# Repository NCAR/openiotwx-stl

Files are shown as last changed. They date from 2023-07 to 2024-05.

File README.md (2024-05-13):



# openIoTwx STL File Repository

## Base Configuration

The base configuration can capture the following:

* temperature / pressure / humidity
* PM2.5

The configuration consists of:

* a 3.8" 3 opening wxOrb (non-imprint)
* a basic shield housing 
* a basic AQ housing (2 part hooded)
* 1 PVC adapter
* 4 PVC rings
* 2 closed endcaps
* 1 vented endcap

**Print time is estimated at 37.5h on Ender 3 S3 at 60mm/s, PLA+**.

| Part | Location | Est. Print Time | Notes | 
|:---:| :---: | :--: | :-- |
| 3.8" Housing (3 opening) | [./housing/orb38_housing_3open.stl](./housing/orb38_housing_3open.stl) | 12h | 20-25% infill; positioned thread side down |
| basic shield housing ( for BME680) | housing (MF) [./shield/mushroom_shield_MF.stl](./shield/mushroom_shield_MF.stl) | 6h | print cup side up / (M) thread down; use limited support to end of thread for stability; 25% infill |
|a basic AQ housing (2 part hooded) | base (M) [./aq/aq_grill_base_M.stl](./aq/aq_grill_base_M.stl); <br/>vented lid [./aq/aq_grill_lid.stl](./aq/aq_grill_lid.stl)  | **base**: 4h; **lid**: 2h | **base**: print on side with tree support (@2% infill), 20-25% infill everywhere else; **lid**: print grill side down, 20-25% infill  |
| PVC adapter | [./pvcadapter/knurled_pvc_adapter_M.stl](./pvcadapter/knurled_pvc_adapter_M.stl) | 3h | print thread side up, 30-40% infill for maximum strength |
| PVC Rings (4x) | [./solarpanel/solarpanel_ring_clamp_11mm.stl](./solarpanel/solarpanel_ring_clamp_11mm.stl) | 6h | print flat side to plate, 30-40% infill for maximum strength |
| Closed endcaps (2x) | [./endcaps/closed_endcap.stl](./endcaps/closed_endcap.stl) | 3h | flat (cap) side to plate, 30-40% infill for maximum strength |
| Vented endcap (1x) | [./endcaps/vented_endcap.stl](./endcaps/vented_endcap.stl) | 1.5h | flat (vented) side to plate, 30-40% infill for maximum strength |

## Project Links

* openIoTwx Hub :  [https://github.com/NCAR/openiotwx-hub](https://github.com/NCAR/openiotwx-hub)

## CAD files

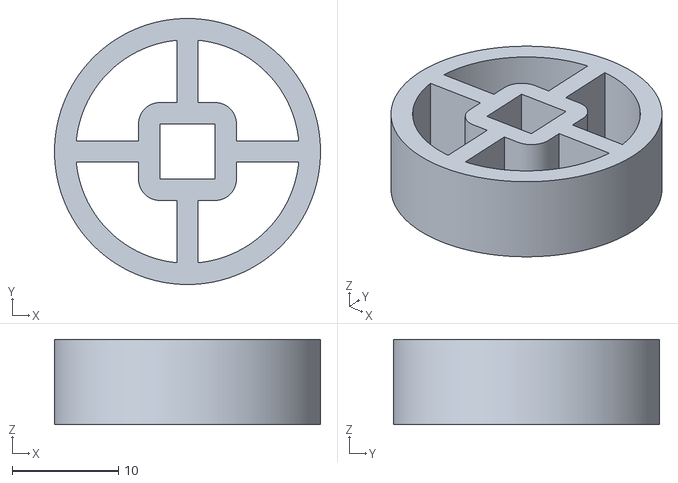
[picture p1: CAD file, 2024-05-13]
accessories/sensor_stand/Inner Base.stl
25.0 x 25.0 x 8.00

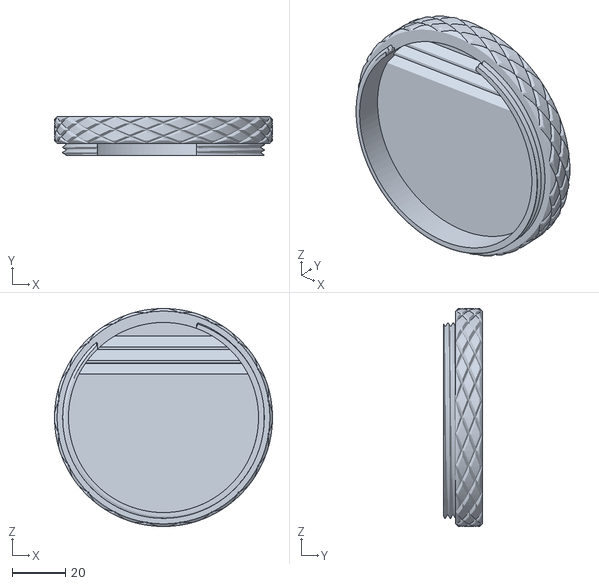
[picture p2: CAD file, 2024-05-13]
aq/aq_grill_lid.stl
82.0 x 14.5 x 82.0

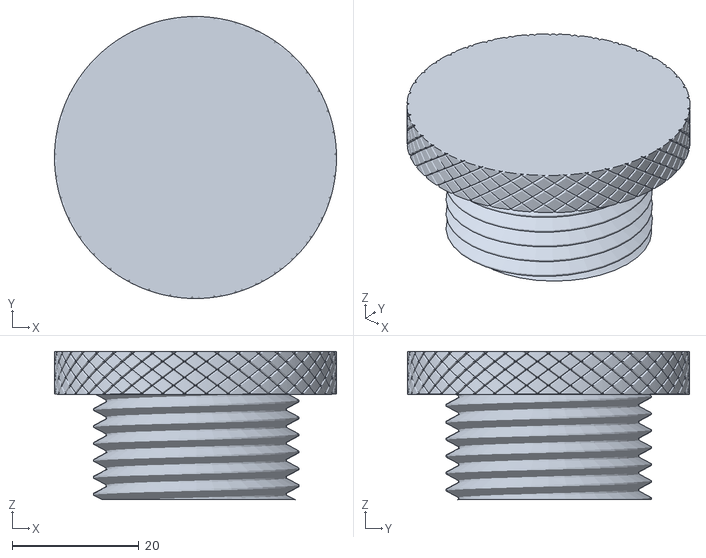
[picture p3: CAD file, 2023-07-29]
endcaps/closed_endcap.stl
44.5 x 44.5 x 23.4

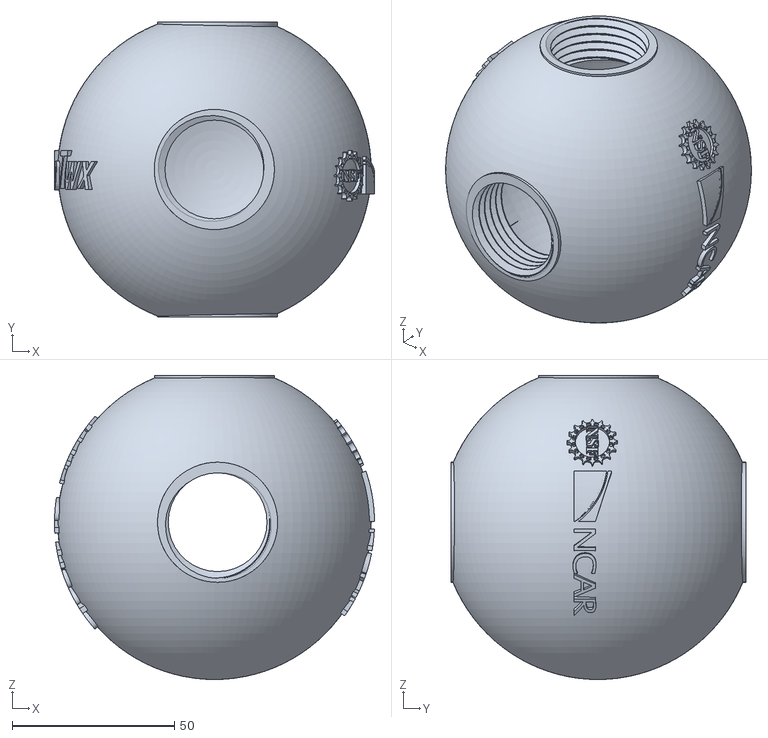
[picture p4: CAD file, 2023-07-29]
housing/orb38_housing_3open.stl
98.5 x 91.0 x 93.6

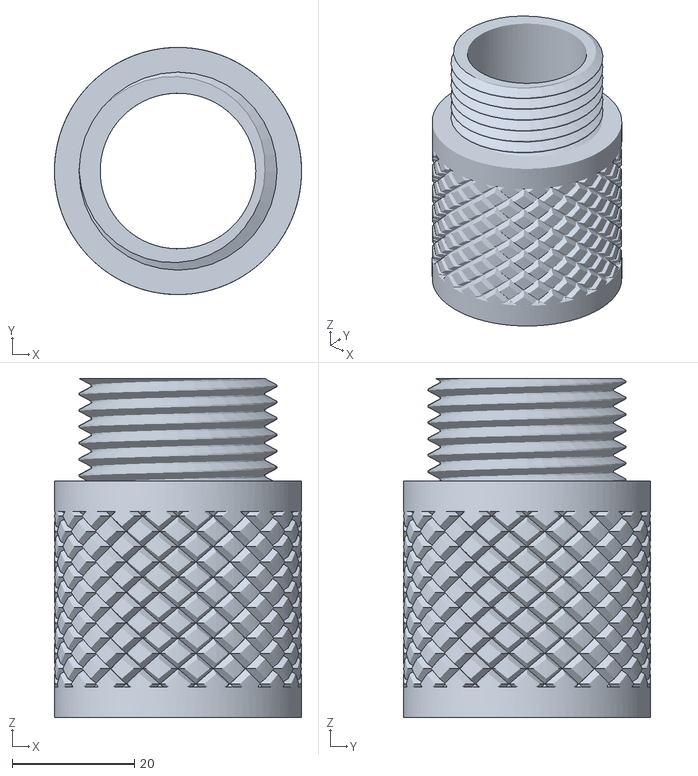
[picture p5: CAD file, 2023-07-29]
pvcadapter/knurled_pvc_adapter_M.stl
40.5 x 40.5 x 55.6

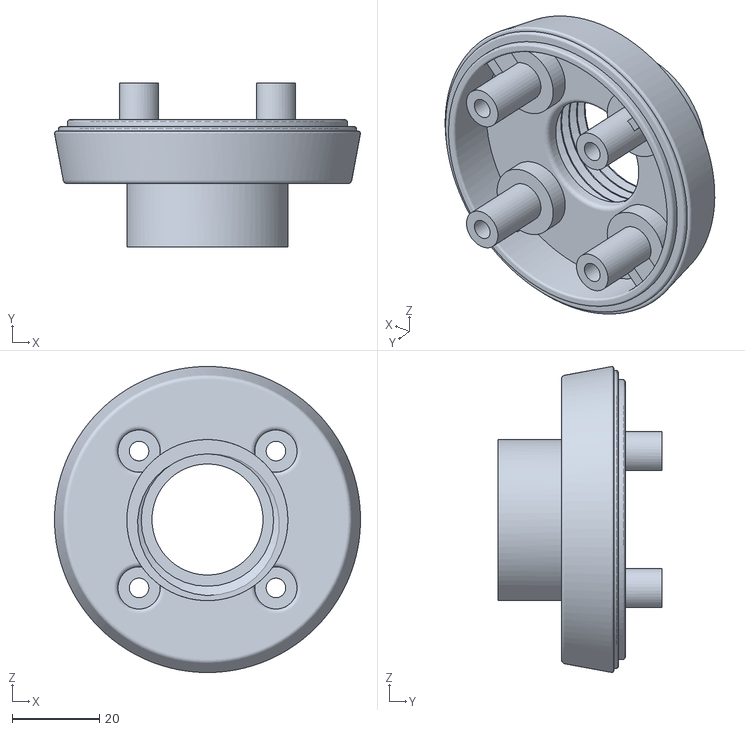
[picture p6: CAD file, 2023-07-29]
rain/rg15_rain_adapter_F.stl
70.3 x 37.6 x 70.3

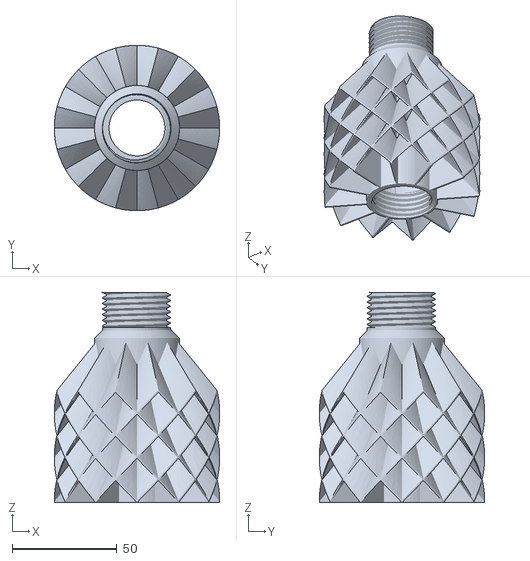
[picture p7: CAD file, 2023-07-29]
shield/pineapple_shield_FM.stl
78.9 x 78.9 x 100.2

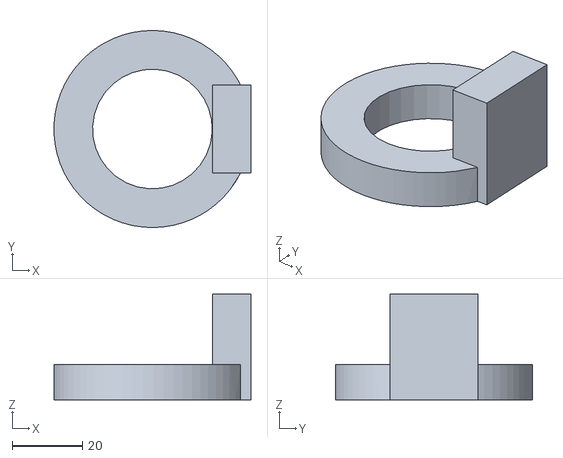
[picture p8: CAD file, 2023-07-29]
solarpanel/solarpanel_ring_clamp_11mm.stl
56.0 x 56.0 x 30.0

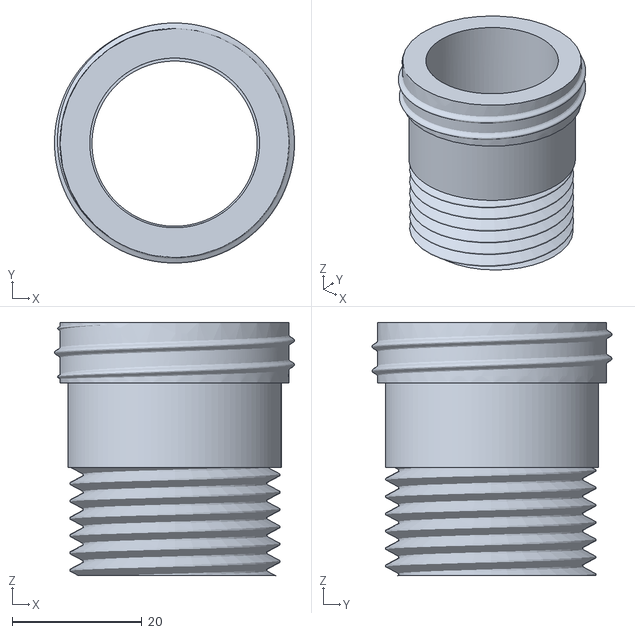
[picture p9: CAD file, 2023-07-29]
uv/uv_tube_M.stl
37.1 x 37.1 x 39.1

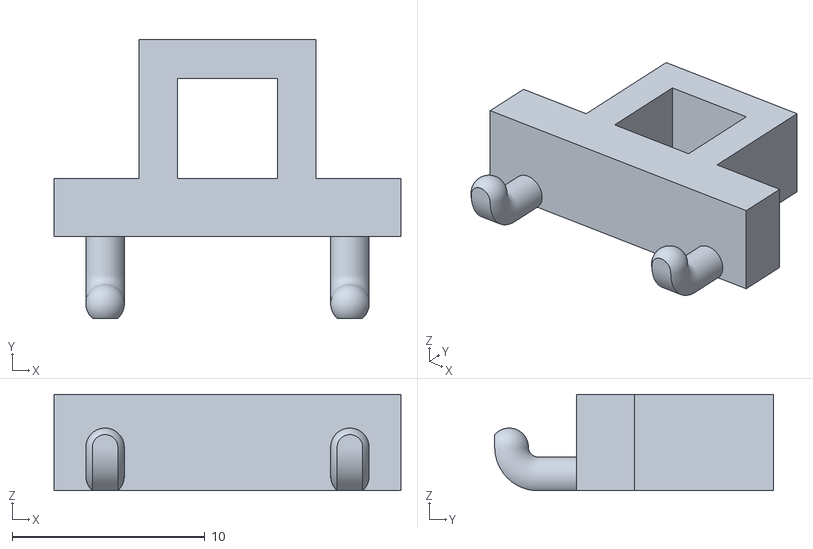
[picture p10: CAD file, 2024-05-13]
accessories/sensor_stand/Sensor Holder v1.stl
18.0 x 14.5 x 5.00

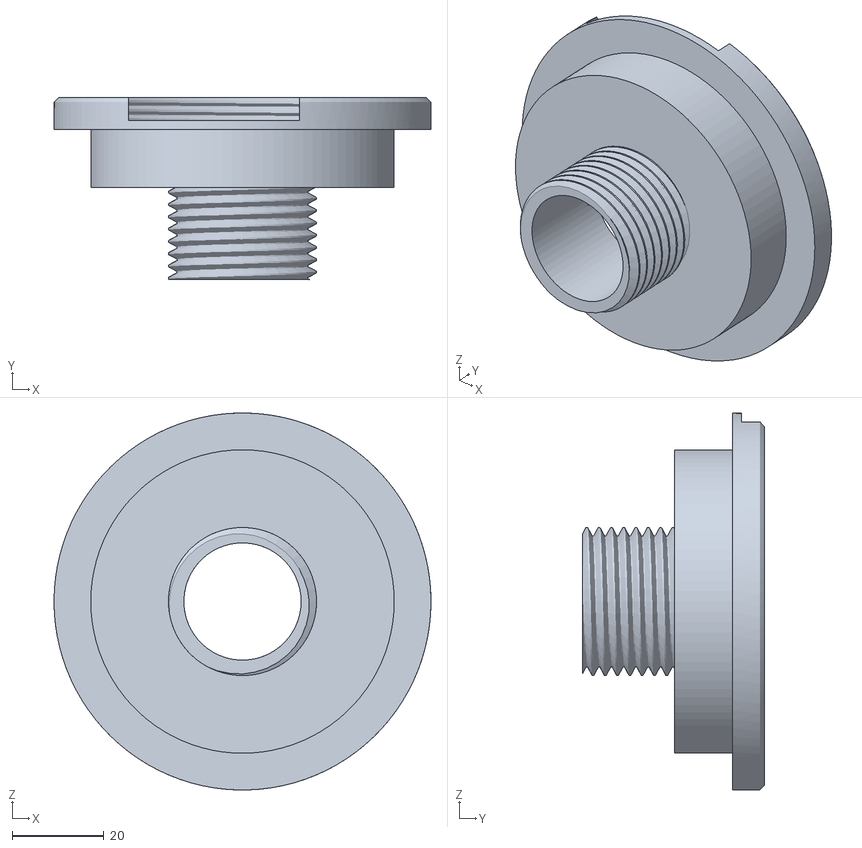
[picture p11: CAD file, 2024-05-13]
aq/aq_grill_base_M.stl
82.0 x 39.6 x 82.0

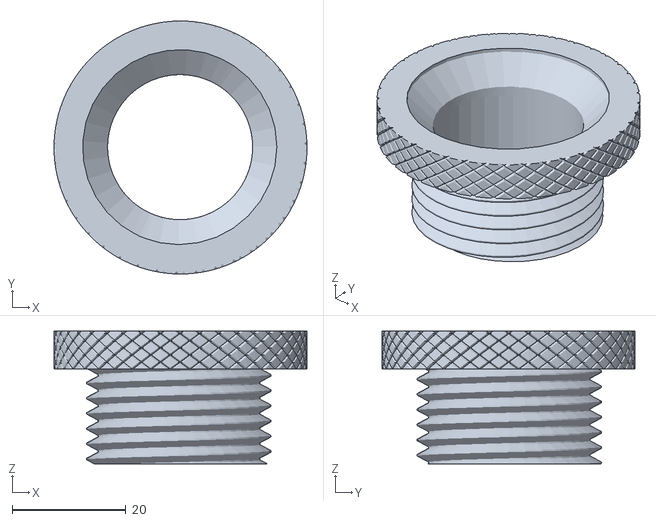
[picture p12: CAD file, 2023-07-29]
endcaps/open_endcap.stl
44.5 x 44.5 x 23.4

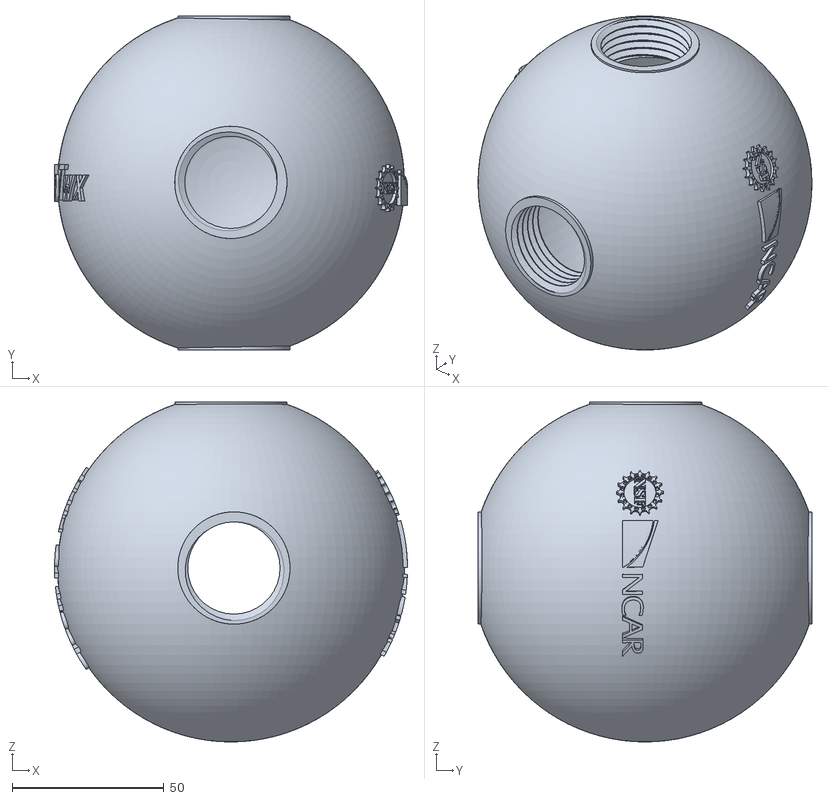
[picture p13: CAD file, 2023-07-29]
housing/orb45_housing_4open.stl
116.3 x 110.0 x 112.0

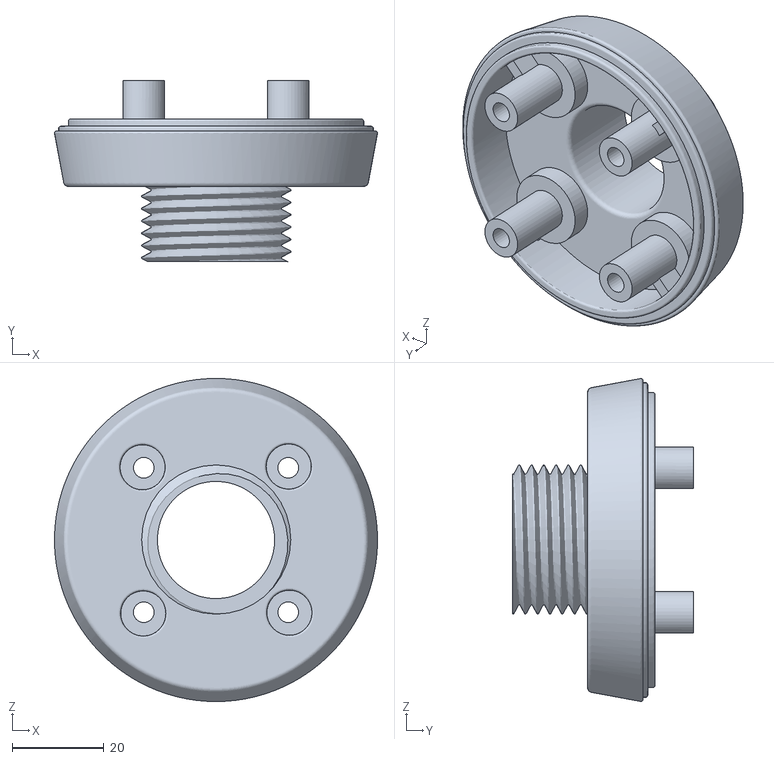
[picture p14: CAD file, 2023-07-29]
rain/rg15_rain_adapter_M.stl
70.3 x 39.5 x 70.3

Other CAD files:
shield/pineapple_shield_MF.stl
uv/uv_tube_F.stl
accessories/sensor_stand/Center Column.stl
aq/aq_base_F.stl
aq/aq_base_M.stl
aq/aq_hood_connecting_FF.stl
aq/aq_hood_connecting_FM.stl
aq/aq_hood_connecting_MF.stl
aq/aq_hood_connecting_MM.stl
aq/aq_hood_terminating_F.stl
aq/aq_hood_terminating_M.stl
aq/aq_vented_locking_lid_F.stl
aq/aq_vented_locking_lid_M.stl
endcaps/vented_endcap.stl
housing/orb38_housing_4open.stl
housing/orb45_housing_5open.stl
uv/uv_topcap.stl

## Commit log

2023-07-29 initial stl sync
    [aq_base_F.stl, aq_base_M.stl, aq_hood_connecting_FF.stl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]
2023-12-18 added 2 part AQ housing
    [aq_grill_base_M.stl, aq_grill_lid.stl]
2024-03-29 updated current vented hood
2024-03-29 updated print instructions
2024-03-29 updated clamps link
2024-03-29 removed old files
    [smallnarrow_housing_3open.stl, smallnarrow_lid_2open.stl]
2024-05-13 added initial sensor stand design
    [Center Column.stl, Inner Base.stl, Sensor Holder v1.stl]
